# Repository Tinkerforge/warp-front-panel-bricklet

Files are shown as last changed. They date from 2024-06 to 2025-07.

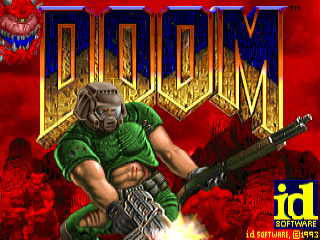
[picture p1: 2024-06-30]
software/tests/doom.png

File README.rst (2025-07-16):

WARP Front Panel Bricklet
=========================

**This Bricklet is currently in development.**

This repository contains the firmware source code and the hardware design
files. The documentation generator configs can be found at
https://github.com/Tinkerforge/generators

Repository Overview
-------------------

.. DO NOT EDIT THIS OVERVIEW MANUALLY! CHANGE https://github.com/Tinkerforge/esp32-firmware/repo_overview.rst AND COPY THAT BLOCK INTO ALL REPOS LISTED BELOW. TODO: AUTOMATE THIS

Software
~~~~~~~~
- `esp32-firmware <https://github.com/Tinkerforge/esp32-firmware>`__  **Please report any issues concerning WARP hard- and software here!** Source code of the ESP32 firmware shared between all WARP Chargers and Energy Managers

- `tfjson <https://github.com/Tinkerforge/tfjson>`__ SAX style JSON serializer and deserializer
- `tfmodbustcp <https://github.com/Tinkerforge/tfmodbustcp>`__ Modbus TCP server and client implementation
- `tfocpp <https://github.com/Tinkerforge/tfocpp>`__ OCPP 1.6 implementation
- `tftools <https://github.com/Tinkerforge/tftools>`__ Miscellaneous tools and helpers

- `esp32-remote-access <https://github.com/Tinkerforge/esp32-remote-access>`__ Source code of the my.warp-charger.com remote access server

- `warp-charger <https://github.com/Tinkerforge/warp-charger>`__ The source code of (docs.)warp-charger.com and the printed manual, released firmwares, datasheets and documents, as well as some tools and hardware design files
- `api.warp-charger.com <https://github.com/Tinkerforge/api.warp-charger.com>`__ Serves APIs that are used by WARP Chargers to obtain relevant public information like day ahead prices
- `vislog.warp-charger.com <https://github.com/Tinkerforge/vislog.warp-charger.com>`__ Visualizes WARP Charger logs and EVSE debug protocols
- `dbus-warp-charger <https://github.com/Tinkerforge/dbus-warp-charger>`__ Integrates WARP Chargers into a Victron Energy Venus OS device (e.g. Cerbo GX)

WARP Charger Hardware
~~~~~~~~~~~~~~~~~~~~~~

- `esp32-brick <https://github.com/Tinkerforge/esp32-brick>`__ Hardware design files of the ESP32 Brick
- `evse-bricklet <https://github.com/Tinkerforge/evse-bricklet>`__  Firmware source code and hardware design files of the EVSE Bricklet
- `rs485-bricklet <https://github.com/Tinkerforge/rs485-bricklet>`__ Firmware source code and hardware design files of the RS485 Bricklet

WARP2 Charger Hardware
~~~~~~~~~~~~~~~~~~~~~~

- `esp32-ethernet-brick <https://github.com/Tinkerforge/esp32-ethernet-brick>`__ Hardware design files of the ESP32 Ethernet Brick
- `evse-v2-bricklet <https://github.com/Tinkerforge/evse-v2-bricklet>`__ Firmware source code and hardware design files of the EVSE 2.0 Bricklet
- `nfc-bricklet <https://github.com/Tinkerforge/nfc-bricklet>`__ Firmware source code and hardware design files of the NFC Bricklet

WARP3 Charger Hardware
~~~~~~~~~~~~~~~~~~~~~~

- `warp-esp32-ethernet-brick <https://github.com/Tinkerforge/warp-esp32-ethernet-brick>`__ Hardware design files of the WARP ESP32 Ethernet Brick
- `evse-v3-bricklet <https://github.com/Tinkerforge/evse-v3-bricklet>`__ Firmware source code and hardware design files of the EVSE 3.0 Bricklet
- `nfc-bricklet <https://github.com/Tinkerforge/nfc-bricklet>`__ Firmware source code and hardware design files of the NFC Bricklet

WARP Energy Manager Hardware
~~~~~~~~~~~~~~~~~~~~~~~~~~~~

- `esp32-ethernet-brick <https://github.com/Tinkerforge/esp32-ethernet-brick>`__ Hardware design files of the ESP32 Ethernet Brick
- `warp-energy-manager-bricklet <https://github.com/Tinkerforge/warp-energy-manager-bricklet>`__ Firmware source code and hardware design files of the WARP Energy Manager Bricklet

WARP Energy Manager 2.0 Hardware
~~~~~~~~~~~~~~~~~~~~~~~~~~~~~~~~

- `esp32-ethernet-brick <https://github.com/Tinkerforge/esp32-ethernet-brick>`__ Hardware design files of the ESP32 Ethernet Brick
- `warp-energy-manager-v2-bricklet <https://github.com/Tinkerforge/warp-energy-manager-v2-bricklet>`__ Firmware source code and hardware design files of the WARP Energy Manager 2.0 Bricklet
- `warp-front-panel-bricklet <https://github.com/Tinkerforge/warp-front-panel-bricklet>`__ Firmware source code and hardware design files of the WARP Front Panel Bricklet

Forked/patched projects
~~~~~~~~~~~~~~~~~~~~~~~

- `arduino-esp32 <https://github.com/Tinkerforge/arduino-esp32>`__
- `esp32-arduino-libs <https://github.com/Tinkerforge/esp32-arduino-libs>`__
- `WireGuard-ESP32-Arduino <https://github.com/Tinkerforge/WireGuard-ESP32-Arduino>`__

Repository Content
------------------

software/:
 * examples/: Examples for all supported languages
 * build/: Compiled files
 * src/: Source code of firmware
 * Makefile: Makefile to build project

hardware/:
 * Contains KiCad project files and additionally schematics as PDF

datasheets/:
 * Contains datasheets for sensors and complex ICs that are used

Hardware
--------

The hardware is designed with the open source EDA Suite KiCad
(http://www.kicad.org). Before you are able to open the files,
you have to install the Tinkerforge kicad-libraries
(https://github.com/Tinkerforge/kicad-libraries). You can either clone
them directly in hardware/ or clone them in a separate folder and
symlink them into hardware/
(ln -s kicad_path/kicad-libraries project_path/hardware). After that you
can open the .pro file in hardware/ with KiCad and from there view and
modify the schematics and the PCB layout.

Software
--------

If you want to do your own Brick/Bricklet firmware development we highly
recommend that you use our build environment setup script and read the
tutorial (https://www.tinkerforge.com/en/doc/Tutorials/Tutorial_Build_Environment/Tutorial.html).

To compile the C code we recommend you to install the newest GNU Arm Embedded
Toolchain (https://launchpad.net/gcc-arm-embedded/+download).
You also need to install bricklib2 (https://github.com/Tinkerforge/bricklib2).

You can either clone it directly in software/src/ or clone it in a
separate folder and symlink it into software/src/
(ln -s bricklib_path/bricklib2 project_path/software/src/). Finally make sure to
have CMake installed (http://www.cmake.org/cmake/resources/software.html).

After that you can build the firmware by invoking make in software/.
The firmware (.zbin) can then be found in software/build/ and uploaded
with brickv (click button "Flashing" on start screen).

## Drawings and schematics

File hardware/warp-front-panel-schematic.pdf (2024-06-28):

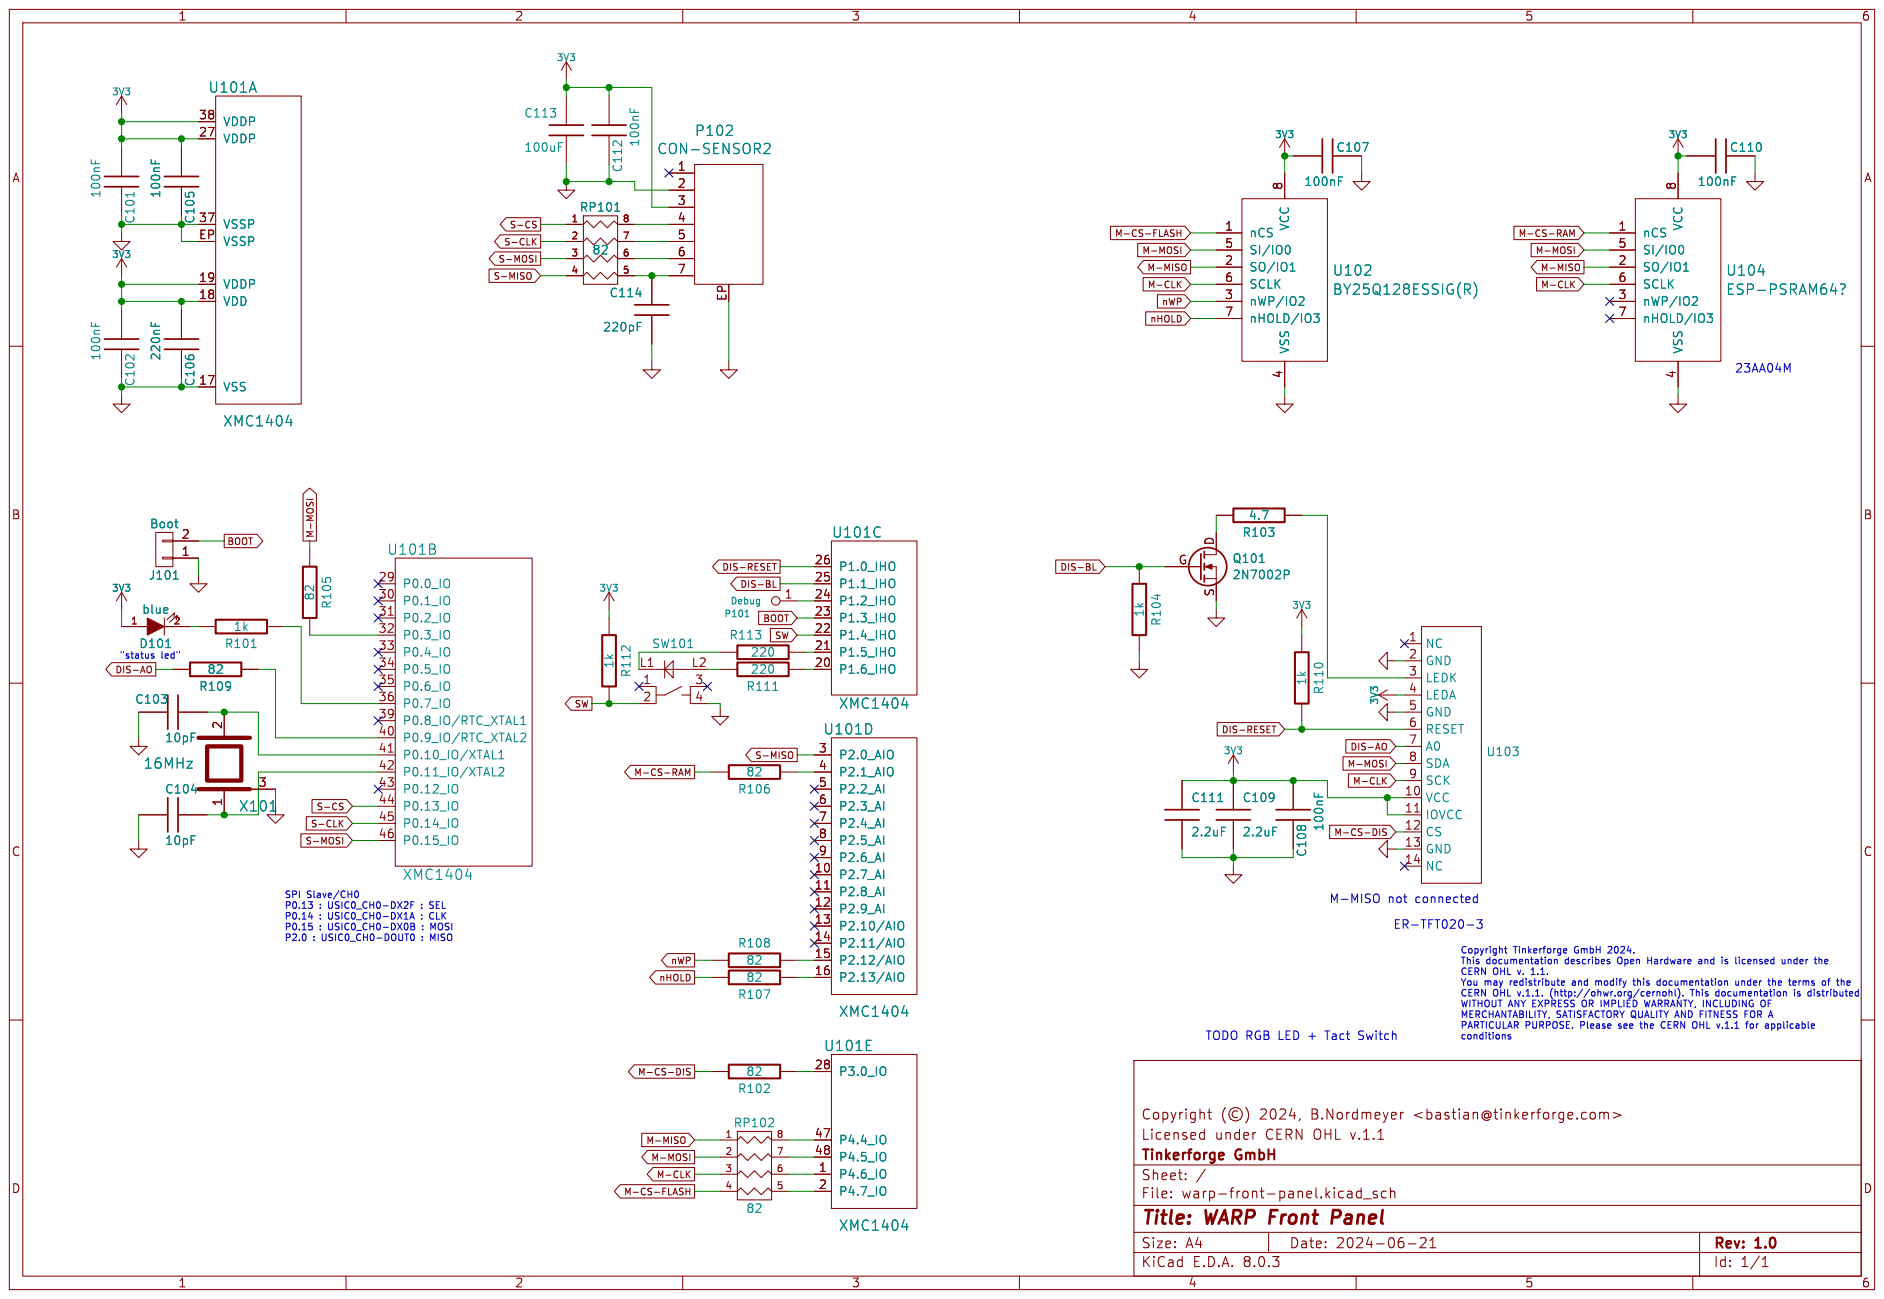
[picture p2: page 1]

M-MISO M-MOSI M-CS-FLASH

M-CLK DIS-BL DIS-RESETBOOT SW

IOVCC 11 CS 12 GND 13 NC 14 GND 2
LEDK 3

conditions ER-TFT020-3 M-MISO not connected

nWP M-CLK M-MISO M-CS-FLASH M-MOSI

PARTICULAR PURPOSE. Please see the CERN OHL v.1.1 for applicable

Id: 1/1 Title: WARP Front Panel File: warp-front-panel.kicad_sch Sheet: / Tinkerforge GmbH

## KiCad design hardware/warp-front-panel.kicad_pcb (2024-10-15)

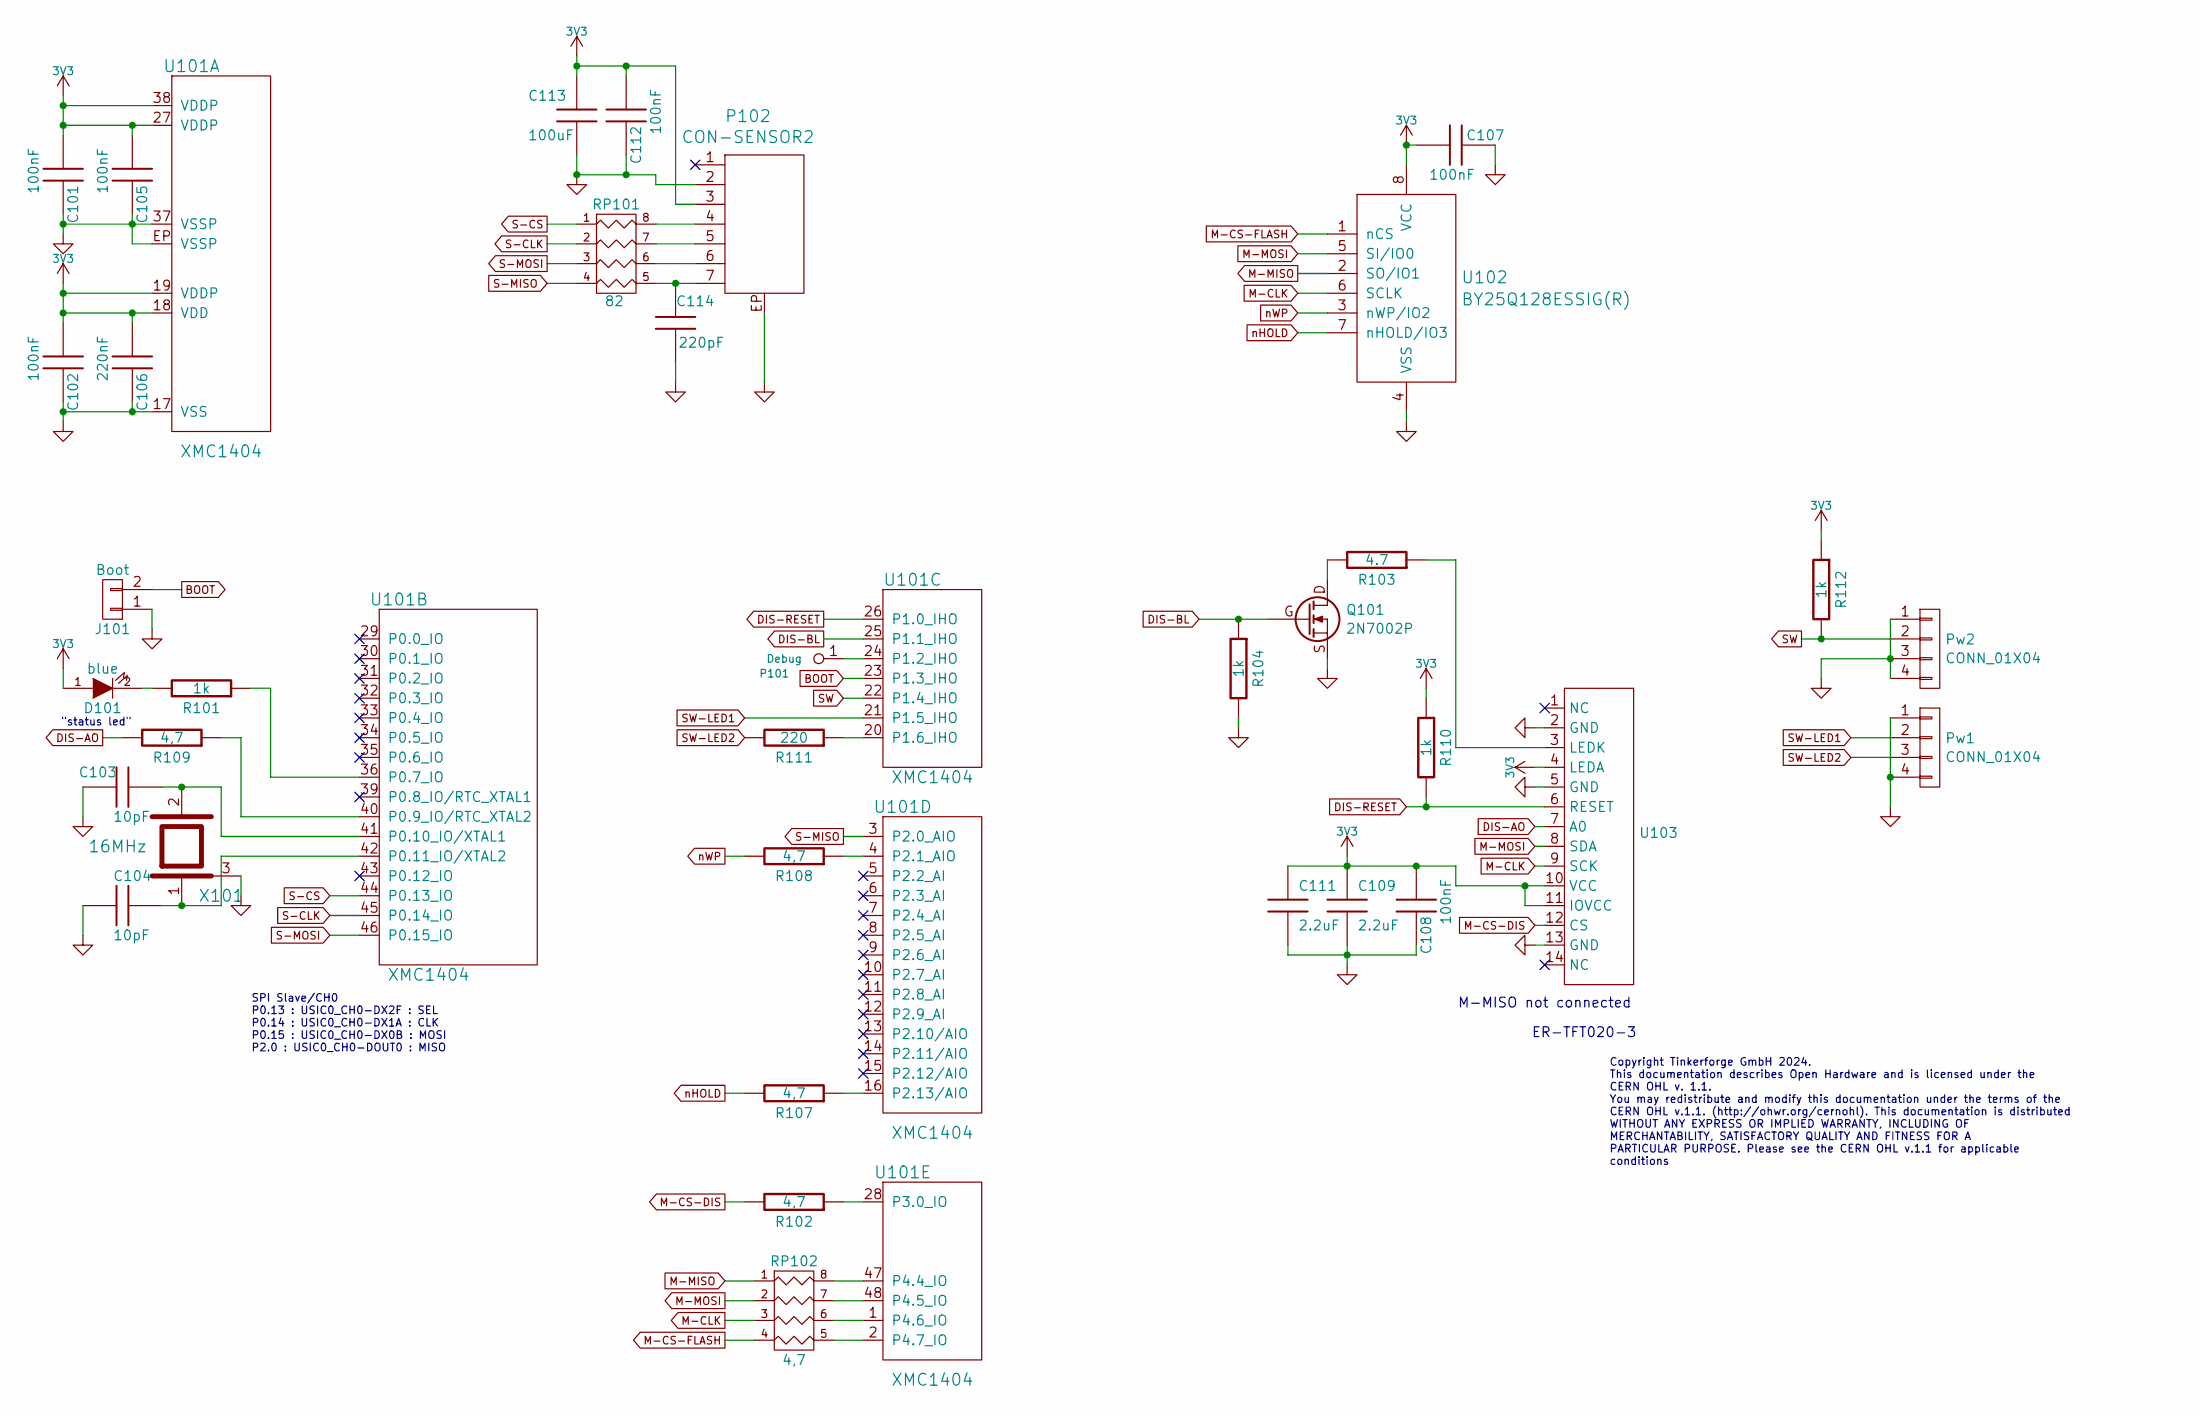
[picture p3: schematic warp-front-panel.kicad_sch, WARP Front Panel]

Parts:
C101, C102, C105, C107, C108, C112: 100nF; C0603F
C103, C104: 10pF; C0603F
C106: 220nF; C0603F
C109, C111: 2.2uF; C0603F
C113: 100uF; C1210
C114: 220pF; C0402F
D101: blue; D0603F
J101: Boot; SolderJumper
P101: Debug; TSTP_STL
P102: CON-SENSOR2; CON-SENSOR2_180
Pw1, Pw2: CONN_01X04; pin_array_1x4-P2mm_D1mm
Q101: 2N7002P; SOT23GDS
R101, R104, R110, R112: 1k; R0603F
R102, R107, R108, R109: 4,7; R0603F
R103: 4.7; R0603F
R111: 220; R0603F
RP101: 82; 4X0402
RP102: 4,7; 4X0402
U101: XMC1404; QFN48-EP2
U102: BY25Q128ESSIG(R); SO-8
U103: ZIF_14P_0.5mm
X101: 16MHz; CRYSTAL_3225

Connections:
3V3: C101.1, C102.1, C105.1, C106.1, C107.1, C108.1, C109.1, C111.1, C112.1, C113.1, D101.1 (A), P102.3, R110.1, R112.1, U101.18 (VDD), U101.19 (VDDP), U101.27 (VDDP), U101.38 (VDDP), U102.8 (VCC), U103.4 (LEDA), U103.10 (VCC), U103.11 (IOVCC)
BOOT: J101.2, U101.23 (P1.3_IHO)
DIS-AO: R109.2, U103.7 (A0)
DIS-BL: Q101.G, R104.1, U101.25 (P1.1_IHO)
DIS-RESET: R110.2, U101.26 (P1.0_IHO), U103.6 (RESET)
GND: C101.2, C102.2, C103.2, C104.2, C105.2, C106.2, C107.2, C108.2, C109.2, C111.2, C112.2, C113.2, C114.2, J101.1, P102.2, P102.EP, Pw1.1, Pw1.4, Pw2.1, Pw2.3, Pw2.4, Q101.S, R104.2, U101.17 (VSS), U101.37 (VSSP), U101.EP (VSSP), U102.4 (VSS), U103.2 (GND), U103.5 (GND), U103.13 (GND), X101.3
M-CLK: RP102.3, U102.6 (SCLK), U103.9 (SCK)
M-CS-DIS: R102.2, U103.12 (CS)
M-CS-FLASH: RP102.4, U102.1 (nCS)
M-MISO: RP102.1, U102.2 (SO/IO1)
M-MOSI: RP102.2, U102.5 (SI/IO0), U103.8 (SDA)
unnamed: D101.2 (K), R101.2
unnamed: Q101.D, R103.2
unnamed: P102.4, RP101.8 (R1)
unnamed: P102.5, RP101.7 (R2)
unnamed: P102.6, RP101.6 (R3)
unnamed: C114.1, P102.7, RP101.5 (R4)
unnamed: RP102.8 (R1), U101.47 (P4.4_IO)
unnamed: RP102.7 (R2), U101.48 (P4.5_IO)
unnamed: RP102.6 (R3), U101.1 (P4.6_IO)
unnamed: RP102.5 (R4), U101.2 (P4.7_IO)
unnamed: R101.1, U101.36 (P0.7_IO)
unnamed: R109.1, U101.40 (P0.9_IO/RTC_XTAL2)
unnamed: C103.1, U101.41 (P0.10_IO/XTAL1), X101.2
unnamed: C104.1, U101.42 (P0.11_IO/XTAL2), X101.1
unnamed: P101.1, U101.24 (P1.2_IHO)
unnamed: R111.1, U101.20 (P1.6_IHO)
unnamed: R108.1, U101.4 (P2.1_AIO)
unnamed: R107.1, U101.16 (P2.13/AIO)
unnamed: R102.1, U101.28 (P3.0_IO)
unnamed: R103.1, U103.3 (LEDK)
S-CLK: RP101.2, U101.45 (P0.14_IO)
S-CS: RP101.1, U101.44 (P0.13_IO)
S-MISO: RP101.4, U101.3 (P2.0_AIO)
S-MOSI: RP101.3, U101.46 (P0.15_IO)
SW: Pw2.2, R112.2, U101.22 (P1.4_IHO)
SW-LED1: Pw1.2, U101.21 (P1.5_IHO)
SW-LED2: Pw1.3, R111.2
nHOLD: R107.2, U102.7 (nHOLD/IO3)
nWP: R108.2, U102.3 (nWP/IO2)

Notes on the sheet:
"status led"
SPI Slave/CH0 P0.13 : USIC0_CH0-DX2F : SEL P0.14 : USIC0_CH0-DX1A : CLK P0.15 : USIC0_CH0-DX0B : MOSI P2.0 : USIC0_CH0-DOUT0 : MISO
M-MISO not connected
Copyright Tinkerforge GmbH 2024. This documentation describes Open Hardware and is licensed under the CERN OHL v. 1.1. You may redistribute and modify this documentation under the terms of the CERN OHL v.1.1. (http://ohwr.org/cernohl). This documentation is distributed WITHOUT ANY EXPRESS OR IMPLIE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
ER-TFT020-3

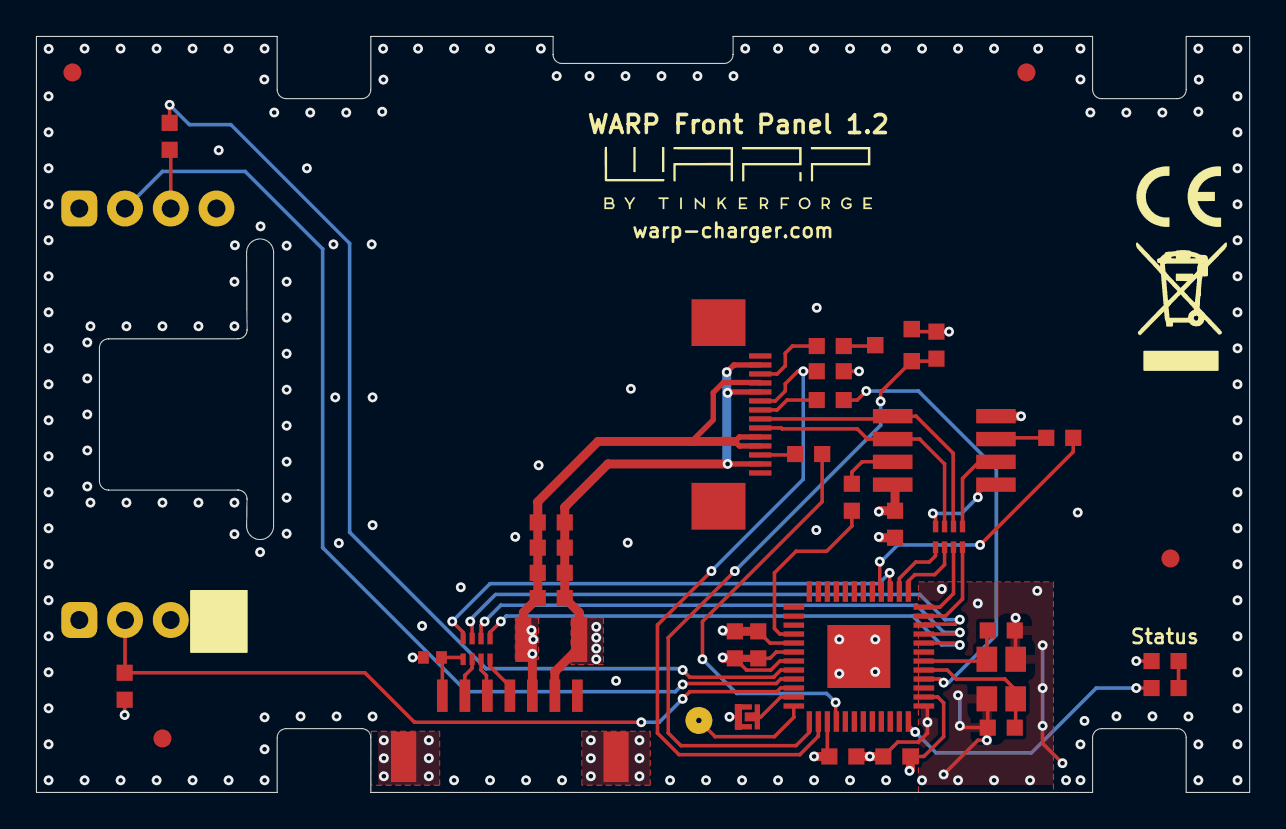
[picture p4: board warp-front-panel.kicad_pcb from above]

Board: 4 copper layers, 67.4 x 42.0 mm, 42 parts (0 on the bottom side), 40 nets.

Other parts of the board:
Fiducial_Mark: VAL**; Fiducial_Mark
Fiducial_Mark#2, Fiducial_Mark#3, Fiducial_Mark#4: VAL**; Fiducial_Mark
VAL: CE_5mm
VAL#2: WEEE_7mm

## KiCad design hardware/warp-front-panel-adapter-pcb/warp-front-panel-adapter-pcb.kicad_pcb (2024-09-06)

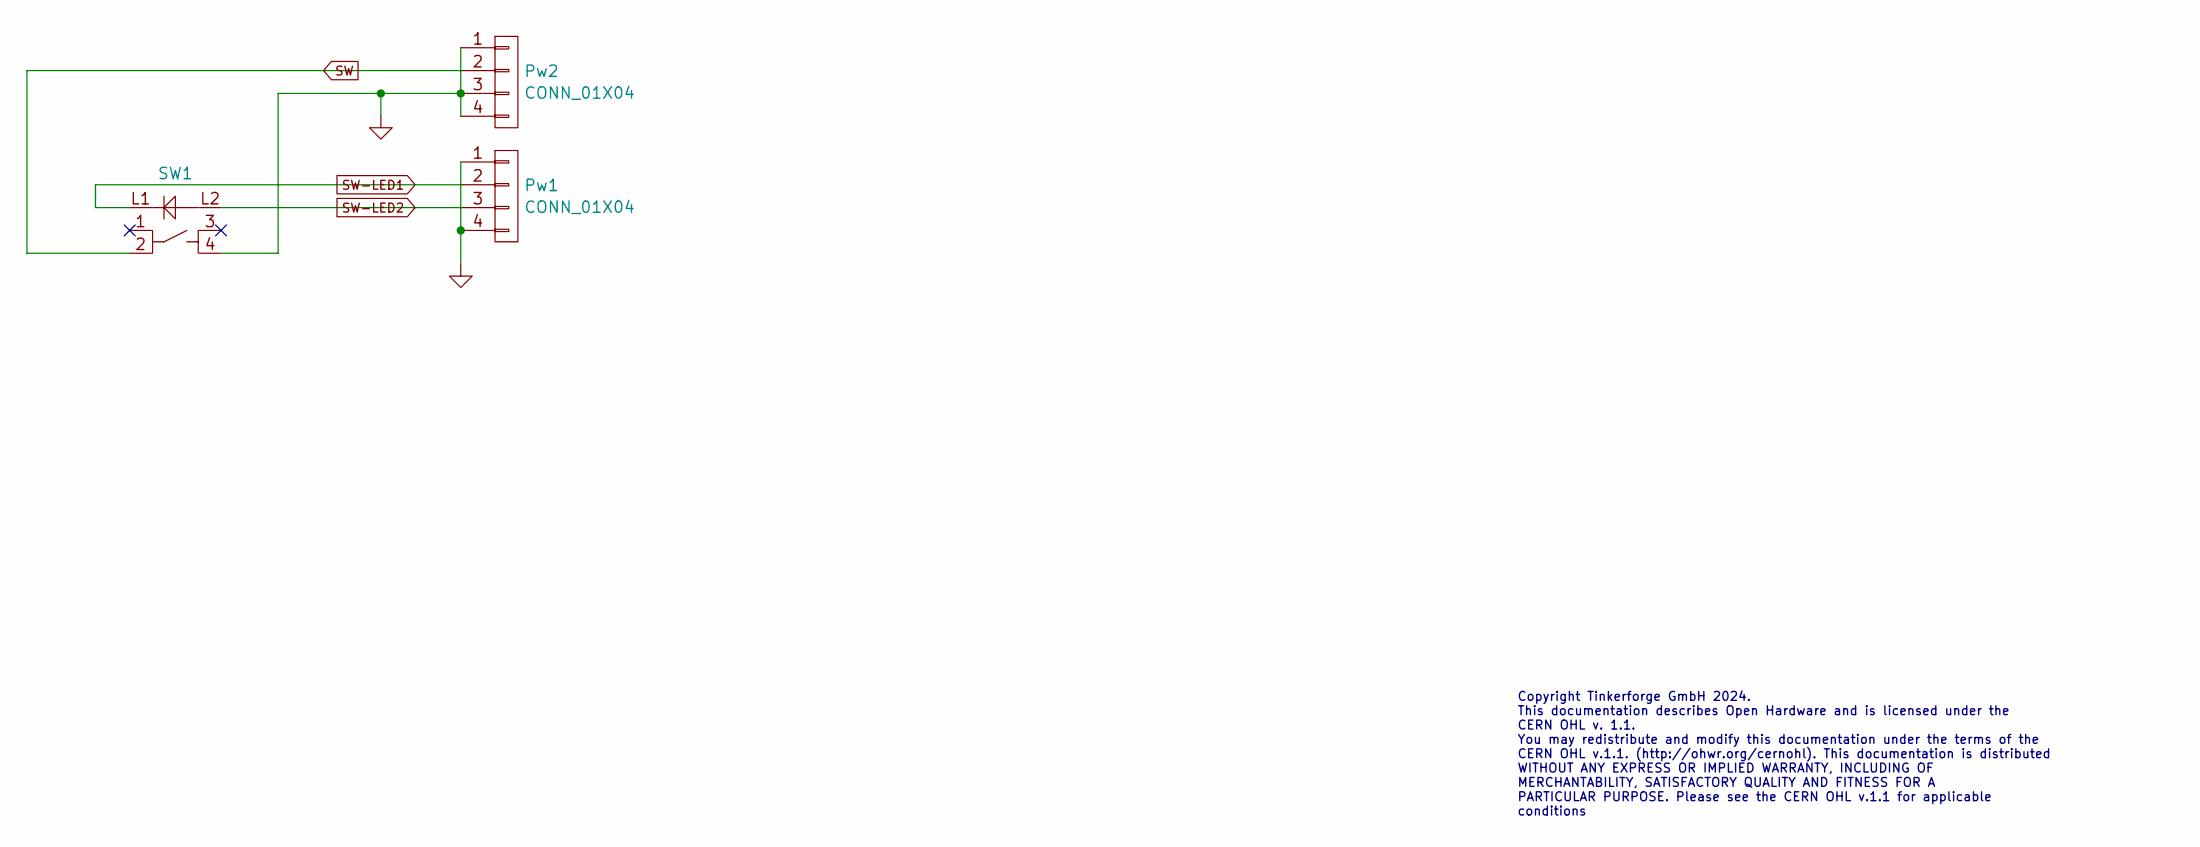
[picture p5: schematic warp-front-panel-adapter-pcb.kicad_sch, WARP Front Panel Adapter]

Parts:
Pw1, Pw2: CONN_01X04; pin_array_1x4-P2mm_D1mm
SW1: LED_TACT_SW_THT

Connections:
GND: Pw1.1, Pw1.4, Pw2.1, Pw2.3, Pw2.4, SW1.4
SW: Pw2.2, SW1.2
SW-LED1: Pw1.2, SW1.L1
SW-LED2: Pw1.3, SW1.L2

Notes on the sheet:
Copyright Tinkerforge GmbH 2024. This documentation describes Open Hardware and is licensed under the CERN OHL v. 1.1. You may redistribute and modify this documentation under the terms of the CERN OHL v.1.1. (http://ohwr.org/cernohl). This documentation is distributed WITHOUT ANY EXPRESS OR IMPLIE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

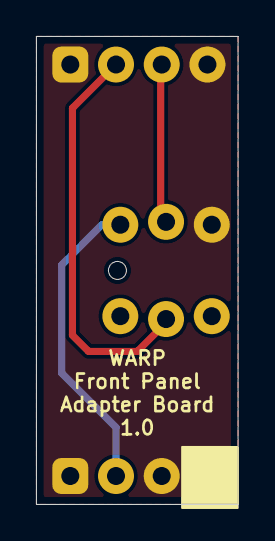
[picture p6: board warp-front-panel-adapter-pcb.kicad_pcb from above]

Board: 2 copper layers, 11.2 x 26.0 mm, 3 parts (1 on the bottom side), 4 nets.

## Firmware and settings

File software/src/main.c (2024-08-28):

/* warp-front-panel-bricklet
 * Copyright (C) 2024 Olaf Lüke <olaf@tinkerforge.com>
 *
 * main.c: Initialization for WARP Front Panel Bricklet
 *
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
 * You should have received a copy of the GNU Lesser General Public
 * License along with this library; if not, write to the
 * Free Software Foundation, Inc., 59 Temple Place - Suite 330,
 * Boston, MA 02111-1307, USA.
 */

#include <stdio.h>
#include <stdbool.h>

#include "configs/config.h"

#include "bricklib2/bootloader/bootloader.h"
#include "bricklib2/hal/system_timer/system_timer.h"
#include "bricklib2/logging/logging.h"
#include "communication.h"

#include "st7789.h"
#include "by25q.h"
#include "button.h"
#include "led.h"
#include "psram.h"
#include "font.h"
#include "sprite.h"
#include "page_front.h"
#include "page_wifi_setup.h"
#include "status_bar.h"
#include "display.h"

int main(void) {
    logging_init();
    logd("Start WARP Front Panel Bricklet\n\r");

    communication_init();
    st7789_init();
    by25q_init();
    button_init();
    led_init();
    psram_init();
    font_init();
    sprite_init();
    page_front_init();
    page_wifi_setup_init();
    status_bar_init();
    display_init();

    while(true) {
        bootloader_tick();
        communication_tick();
        st7789_tick();
        by25q_tick();
        button_tick();
        led_tick();
        psram_tick();
    }
}

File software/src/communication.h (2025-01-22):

/* warp-front-panel-bricklet
 * Copyright (C) 2025 Olaf Lüke <olaf@tinkerforge.com>
 *
 * communication.h: TFP protocol message handling
 *
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
 * You should have received a copy of the GNU Lesser General Public
 * License along with this library; if not, write to the
 * Free Software Foundation, Inc., 59 Temple Place - Suite 330,
 * Boston, MA 02111-1307, USA.
 */

#ifndef COMMUNICATION_H
#define COMMUNICATION_H

#include <stdint.h>
#include <stdbool.h>

#include "bricklib2/protocols/tfp/tfp.h"
#include "bricklib2/bootloader/bootloader.h"

// Default functions
BootloaderHandleMessageResponse handle_message(const void *data, void *response);
void communication_tick(void);
void communication_init(void);

// Constants

#define WARP_FRONT_PANEL_FLASH_STATUS_OK 0
#define WARP_FRONT_PANEL_FLASH_STATUS_BUSY 1

#define WARP_FRONT_PANEL_LED_PATTERN_OFF 0
#define WARP_FRONT_PANEL_LED_PATTERN_ON 1
#define WARP_FRONT_PANEL_LED_PATTERN_BLINKING 2
#define WARP_FRONT_PANEL_LED_PATTERN_BREATHING 3

#define WARP_FRONT_PANEL_LED_COLOR_GREEN 0
#define WARP_FRONT_PANEL_LED_COLOR_RED 1
#define WARP_FRONT_PANEL_LED_COLOR_YELLOW 2

#define WARP_FRONT_PANEL_DISPLAY_OFF 0
#define WARP_FRONT_PANEL_DISPLAY_AUTOMATIC 1

#define WARP_FRONT_PANEL_BOOTLOADER_MODE_BOOTLOADER 0
#define WARP_FRONT_PANEL_BOOTLOADER_MODE_FIRMWARE 1
#define WARP_FRONT_PANEL_BOOTLOADER_MODE_BOOTLOADER_WAIT_FOR_REBOOT 2
#define WARP_FRONT_PANEL_BOOTLOADER_MODE_FIRMWARE_WAIT_FOR_REBOOT 3
#define WARP_FRONT_PANEL_BOOTLOADER_MODE_FIRMWARE_WAIT_FOR_ERASE_AND_REBOOT 4

#define WARP_FRONT_PANEL_BOOTLOADER_STATUS_OK 0
#define WARP_FRONT_PANEL_BOOTLOADER_STATUS_INVALID_MODE 1
#define WARP_FRONT_PANEL_BOOTLOADER_STATUS_NO_CHANGE 2
#define WARP_FRONT_PANEL_BOOTLOADER_STATUS_ENTRY_FUNCTION_NOT_PRESENT 3
#define WARP_FRONT_PANEL_BOOTLOADER_STATUS_DEVICE_IDENTIFIER_INCORRECT 4
#define WARP_FRONT_PANEL_BOOTLOADER_STATUS_CRC_MISMATCH 5

#define WARP_FRONT_PANEL_STATUS_LED_CONFIG_OFF 0
#define WARP_FRONT_PANEL_STATUS_LED_CONFIG_ON 1
#define WARP_FRONT_PANEL_STATUS_LED_CONFIG_SHOW_HEARTBEAT 2
#define WARP_FRONT_PANEL_STATUS_LED_CONFIG_SHOW_STATUS 3

// Function and callback IDs and structs
#define FID_SET_FLASH_INDEX 1
#define FID_GET_FLASH_INDEX 2
#define FID_SET_FLASH_DATA 3
#define FID_ERASE_FLASH_SECTOR 4
#define FID_ERASE_FLASH 5
#define FID_SET_STATUS_BAR 6
#define FID_GET_STATUS_BAR 7
#define FID_SET_DISPLAY_PAGE_INDEX 8
#define FID_GET_DISPLAY_PAGE_INDEX 9
#define FID_SET_DISPLAY_FRONT_PAGE_ICON 10
#define FID_GET_DISPLAY_FRONT_PAGE_ICON 11
#define FID_SET_DISPLAY_WIFI_SETUP_1 12
#define FID_GET_DISPLAY_WIFI_SETUP_1 13
#define FID_SET_DISPLAY_WIFI_SETUP_2 14
#define FID_GET_DISPLAY_WIFI_SETUP_2 15
#define FID_SET_LED_STATE 16
#define FID_GET_LED_STATE 17
#define FID_SET_DISPLAY 18
#define FID_GET_DISPLAY 19
#define FID_GET_FLASH_METADATA 20
#define FID_REDRAW_EVERYTHING 22

#define FID_CALLBACK_FLASH_DATA_DONE 21

typedef struct {
    TFPMessageHeader header;
    uint32_t page_index;
    uint8_t sub_page_index;
} __attribute__((__packed__)) SetFlashIndex;

typedef struct {
    TFPMessageHeader header;
} __attribute__((__packed__)) GetFlashIndex;

typedef struct {
    TFPMessageHeader header;
    uint32_t page_index;
    uint8_t sub_page_index;
} __attribute__((__packed__)) GetFlashIndex_Response;

typedef struct {
    TFPMessageHeader header;
    uint8_t data[64];
} __attribute__((__packed__)) SetFlashData;

typedef struct {
    TFPMessageHeader header;
    uint32_t next_page_index;
    uint8_t next_sub_page_index;
    uint8_t status;
} __attribute__((__packed__)) SetFlashData_Response;

typedef struct {
    TFPMessageHeader header;
    uint16_t sector_index;
} __attribute__((__packed__)) EraseFlashSector;

typedef struct {
    TFPMessageHeader header;
    uint8_t status;
} __attribute__((__packed__)) EraseFlashSector_Response;

typedef struct {
    TFPMessageHeader header;
} __attribute__((__packed__)) EraseFlash;

typedef struct {
    TFPMessageHeader header;
    uint8_t status;
} __attribute__((__packed__)) EraseFlash_Response;

typedef struct {
    TFPMessageHeader header;
    uint32_t ethernet_status;
    uint32_t wifi_status;
    uint8_t hours;
    uint8_t minutes;
    uint8_t seconds;
} __attribute__((__packed__)) SetStatusBar;

typedef struct {
    TFPMessageHeader header;
} __attribute__((__packed__)) GetStatusBar;

typedef struct {
    TFPMessageHeader header;
    uint32_t ethernet_status;
    uint32_t wifi_status;
    uint8_t hours;
    uint8_t minutes;
    uint8_t seconds;
} __attribute__((__packed__)) GetStatusBar_Response;

typedef struct {
    TFPMessageHeader header;
    uint32_t page_index;
} __attribute__((__packed__)) SetDisplayPageIndex;

typedef struct {
    TFPMessageHeader header;
} __attribute__((__packed__)) GetDisplayPageIndex;

typedef struct {
    TFPMessageHeader header;
    uint32_t page_index;
} __attribute__((__packed__)) GetDisplayPageIndex_Response;

typedef struct {
    TFPMessageHeader header;
    uint32_t icon_index;
    bool active;
    uint32_t sprite_index;
    char text_1[6];
    uint8_t font_index_1;
    char text_2[6];
    uint8_t font_index_2;
} __attribute__((__packed__)) SetDisplayFrontPageIcon;

typedef struct {
    TFPMessageHeader header;
    uint32_t icon_index;
} __attribute__((__packed__)) GetDisplayFrontPageIcon;

typedef struct {
    TFPMessageHeader header;
    bool active;
    uint32_t sprite_index;
    char text_1[10];
    uint8_t font_index_1;
    char text_2[10];
    uint8_t font_index_2;
} __attribute__((__packed__)) GetDisplayFrontPageIcon_Response;

typedef struct {
    TFPMessageHeader header;
    char ip_address[15];
    char ssid[49];
} __attribute__((__packed__)) SetDisplayWifiSetup1;

typedef struct {
    TFPMessageHeader header;
} __attribute__((__packed__)) GetDisplayWifiSetup1;

typedef struct {
    TFPMessageHeader header;
    char ip_address[15];
    char ssid[49];
} __attribute__((__packed__)) GetDisplayWifiSetup1_Response;

typedef struct {
    TFPMessageHeader header;
    char password[64];
} __attribute__((__packed__)) SetDisplayWifiSetup2;

typedef struct {
    TFPMessageHeader header;
} __attribute__((__packed__)) GetDisplayWifiSetup2;

typedef struct {
    TFPMessageHeader header;
    char password[64];
} __attribute__((__packed__)) GetDisplayWifiSetup2_Response;

typedef struct {
    TFPMessageHeader header;
    uint8_t pattern;
    uint8_t color;
} __attribute__((__packed__)) SetLEDState;

typedef struct {
    TFPMessageHeader header;
} __attribute__((__packed__)) GetLEDState;

typedef struct {
    TFPMessageHeader header;
    uint8_t pattern;
    uint8_t color;
} __attribute__((__packed__)) GetLEDState_Response;

typedef struct {
    TFPMessageHeader header;
    uint8_t display;
} __attribute__((__packed__)) SetDisplay;

typedef struct {
    TFPMessageHeader header;
} __attribute__((__packed__)) GetDisplay;
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

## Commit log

2024-06-13 Initial commit of autogenerated stub firmware
    [cmake_config_custom.txt]
2024-06-18 add partial prototype
    [warp-front-panel.kicad_pcb, warp-front-panel.kicad_sch]
2024-06-21 prototype version
    [warp-front-panel.kicad_pcb, warp-front-panel.kicad_sch]
2024-06-28 add schematic
2024-06-28 fix signal directions
    [warp-front-panel.kicad_sch]
2024-06-29 Add stub implementation for button and PSRAM
2024-06-29 Use correct select define
    [st7789.c]
2024-06-30 Add SPI transceive option for no select and no deselect
2024-06-30 Add task that reads from BY25Q flash and writes to ST7789 driver
2024-06-30 Add test code that can be switched on/off with ifdef
2024-07-03 Add options to SPI transceive and add erase functions to BY25Q flash
2024-07-03 Force ST7789 to never block the SPI bus completely
    If there is data to write to the by25q, we wait here until it is written.
    This makes sure that there can be at least on write to the by25q per write to the display.
    Otherwise the st7789 could block the SPI bus.
2024-07-15 Add button press with debounce support
    Also include LED testing here for now, will be removed later
2024-07-15 Split ST7789 driver in driver and display util functions
2024-07-16 Add kicad hardware temp files to gitignore
2024-07-17 updated design V1.2
    [warp-front-panel.kicad_pcb, warp-front-panel.kicad_sch]
2024-07-17 added adapter pcb
    [warp-front-panel-adapter-pcb.kicad_pcb, warp-front-panel-adapter-pcb.kicad_sch]
2024-07-17 change hole
    [warp-front-panel-adapter-pcb.kicad_pcb]
2024-07-17 improve routing
    [warp-front-panel.kicad_pcb, warp-front-panel.kicad_sch]
2024-08-28 Fix pin defines
2024-08-28 Implement LED API
2024-08-29 Make sure PWM is synced and uses maximum brightness (for yellow color)
2024-08-29 Add and implement API to turn display off/automatic
    In automatic mode it will turn off after 60 minutes and
    enable again on button press.
2024-09-06 changed data resistor values to 4,7Ohm
    [warp-front-panel-adapter-pcb.kicad_pcb, warp-front-panel.kicad_pcb, warp-front-panel.kicad_sch]
2024-09-14 Add startup defaults for LED and wifi setup
2024-09-14 Add metadata to flashmap
    Currently includes version, length and checksum, but can
    be extended later on.
2024-09-16 sprites: Add sprite source SVGs.
    Some are recreated, so they currently don't match the sprites perfectly.
2024-09-16 Make sure backlight is off by default and when display is inactive
    Also turn display on after reset only after first page is drawn.
    [st7789.c]
2024-10-15 Hardware: Updated Version number
    [warp-front-panel.kicad_pcb]

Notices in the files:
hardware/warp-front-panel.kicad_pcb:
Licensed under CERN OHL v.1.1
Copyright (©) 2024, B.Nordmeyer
